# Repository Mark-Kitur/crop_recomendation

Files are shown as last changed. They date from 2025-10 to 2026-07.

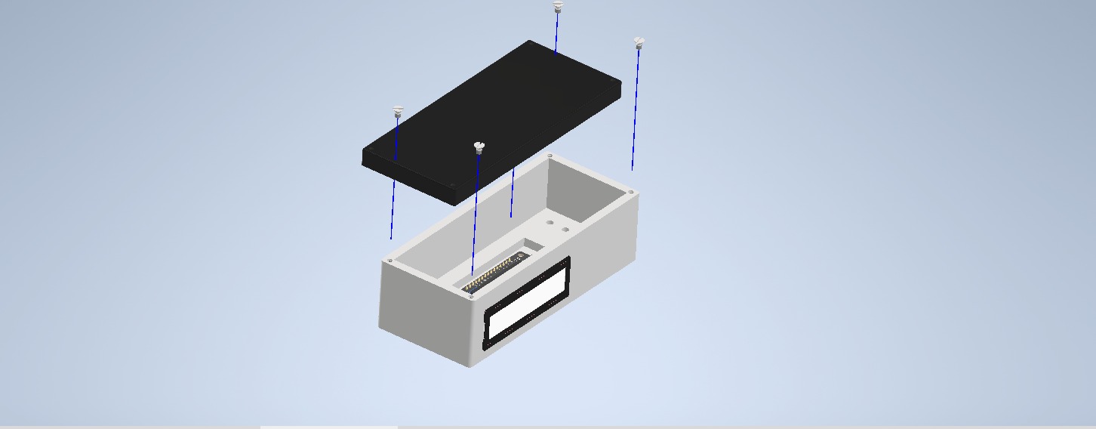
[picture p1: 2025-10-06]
3D Model Images/Assembly.jpeg

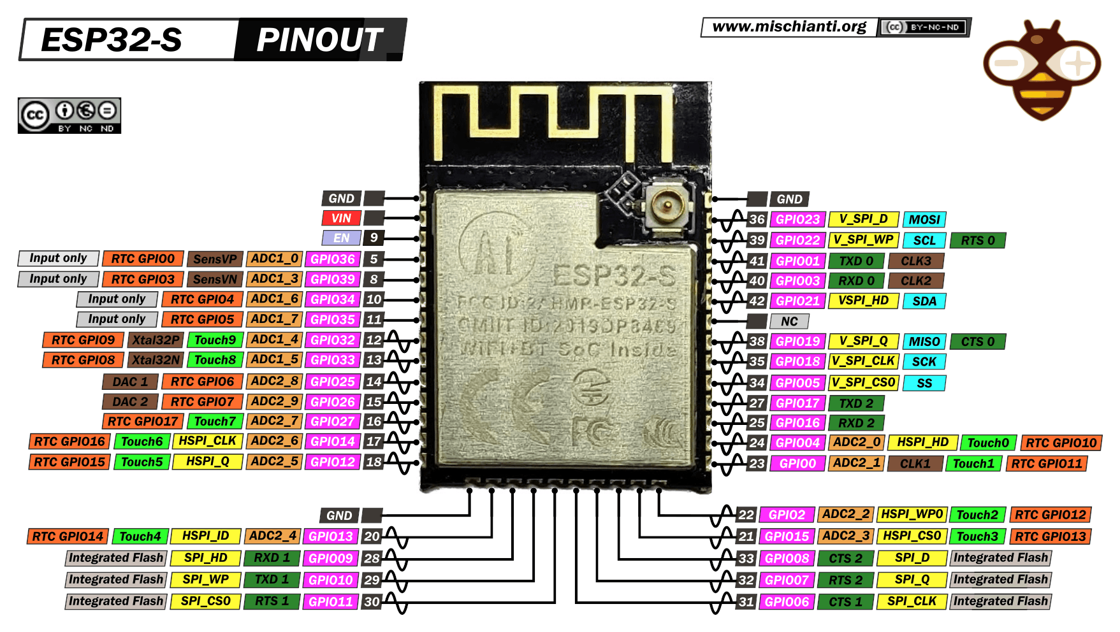
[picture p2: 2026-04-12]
PCB_V2/ESP32-S-pinout-mischianti-high-resolution.png

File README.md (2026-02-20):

**Smart Crop Recommendation System**

link to the video: https://youtu.be/nVsl1SV6peM?si=QAl62YudmvHhIrHM

**Overview**

This project implements a Crop Recommendation System that suggests the most suitable crop to grow based on soil nutrients and environmental conditions. It combines Machine Learning (ML) with IoT (ESP8266 microcontroller) to support precision agriculture.
The workflow:
Collected and preprocessed agricultural data (soil nutrients & climate).
Trained a Random Forest Classifier model to recommend crops.
 Built a Flask web application for user-friendly crop prediction and farming advice.
 Converted the trained ML model to C code (micromlgen) and deployed it on an ESP8266 NodeMCU microcontroller.

Dataset
The dataset includes soil and environmental features:
N: Nitrogen content ratio in soil
P: Phosphorus content ratio in soil
K: Potassium content ratio in soil
Temperature: in °C
Humidity: in %
pH: Soil acidity/alkalinity
Rainfall: in mm

Tech Stack

Machine Learning: Random Forest Classifier (scikit-learn)

Web Framework: Ruby and Flask

Frontend: HTML, CSS (simple UI for predictions)

Microcontroller: ESP8266 (NodeMCU)

TinyML Library: micromlgen for C model export

Flask Web App
The web app allows users to:
Input soil & environmental parameters.
Get the best crop recommendation.
Receive advice on optimizing conditions (nutrients, pH, rainfall, etc.).

**Ruby Backend With ONNX Runtime**
The second deployment path validates language-agnostic inference by converting the trained Random Forest model to ONNX format.

Key Steps

Export trained model from Python → ONNX

Load ONNX model in Ruby using onnxruntime gem

Run inference directly from Ruby backend code

Serve predictions to a lightweight Ruby-based web endpoint or CLI script

Purpose

Demonstrates cross-platform, cross-language model deployment

Makes the engine compatible with Ruby web stacks (e.g., Rails, Sinatra)

Confirms interoperability without retraining or rewriting ML code

Ruby Deployment Capabilities

The Ruby ONNX version can:

Accept soil parameters via a web form or API

Run fast inference locally using ONNX Runtime

Return the crop recommendation + condition improvement notes

**ESP8266 Deployment**
The trained Random Forest model was converted into C code.
Deployed on ESP8266 NodeMCU with:
DHT11 sensor for temperature & humidity.
LCD display to show predicted crop.
Random values (for testing) simulating N, P, K, pH, rainfall.
Feel free to fork, improve, or suggest enhancements. Together, let’s make farming smarter

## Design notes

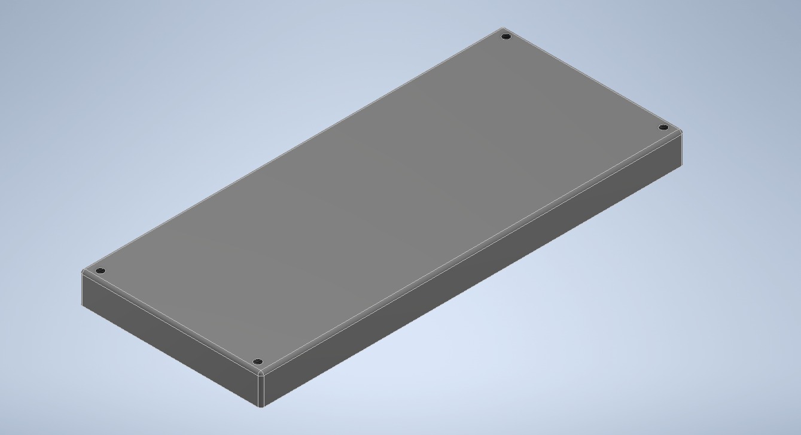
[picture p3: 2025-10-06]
3D Model Images/Top.jpeg

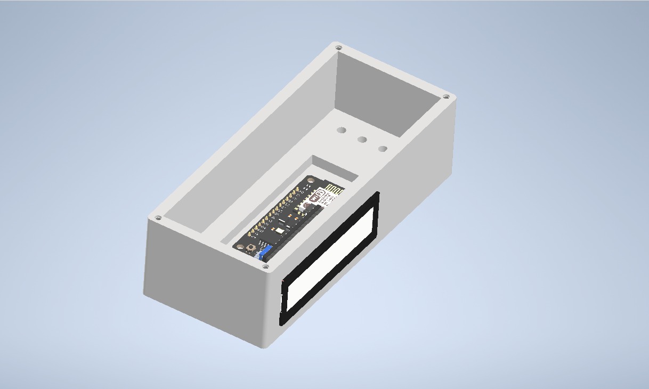
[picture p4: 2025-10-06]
3D Model Images/Base.jpeg

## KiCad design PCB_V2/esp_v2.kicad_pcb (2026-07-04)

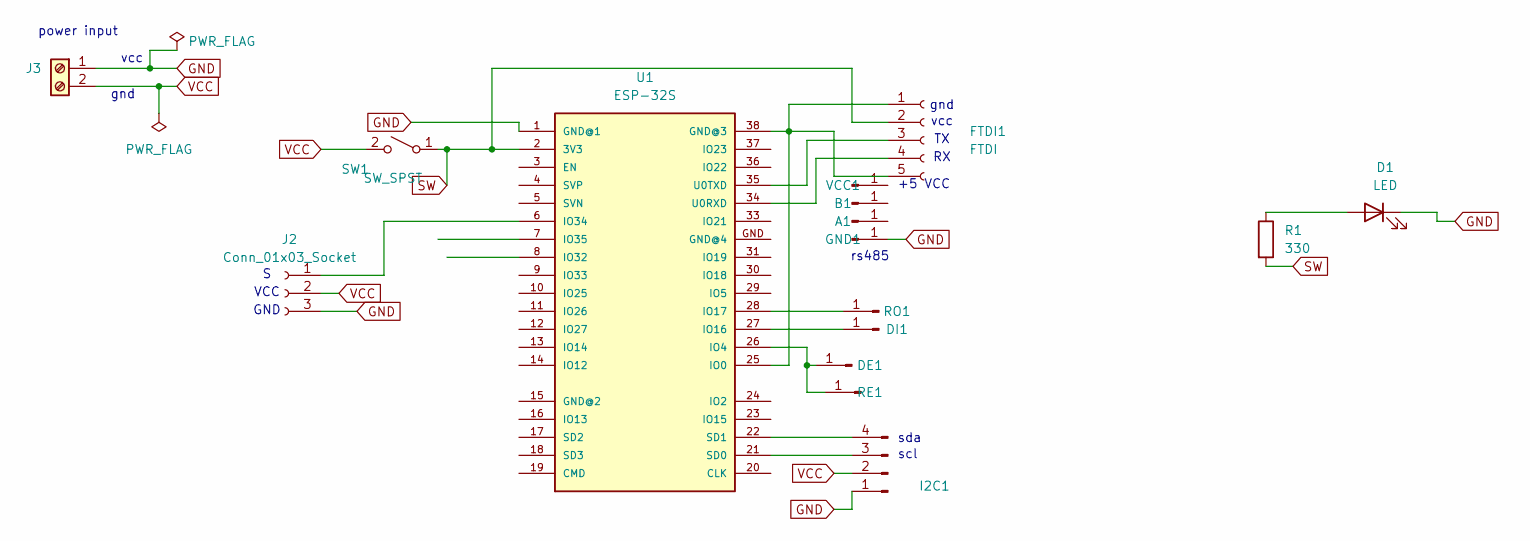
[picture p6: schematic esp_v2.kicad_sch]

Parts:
A1: Conn_01x01_Pin; PinHeader_1x01_P2.54mm_Vertical
B1: Conn_01x01_Pin; PinHeader_1x01_P2.54mm_Vertical
D1: LED; LED_D1.8mm_W3.3mm_H2.4mm
DE1: Conn_01x01_Pin; PinHeader_1x01_P2.54mm_Vertical
DI1: DI; PinHeader_1x01_P2.54mm_Vertical
FTDI1: FTDI; PinSocket_1x05_P2.54mm_Vertical
GND1: Conn_01x01_Pin; PinHeader_1x01_P2.54mm_Vertical
I2C1: Conn_01x04_Pin; PinHeader_1x04_P2.54mm_Vertical
J2: Conn_01x03_Socket; PinSocket_1x03_P2.54mm_Vertical
J3: Screw_Terminal_01x02; TerminalBlock_4Ucon_1x02_P3.50mm_Vertical
R1: 330; R_0815_2038Metric_Pad1.20x4.05mm_HandSolder
RE1: Conn_01x01_Pin; PinHeader_1x01_P2.54mm_Vertical
RO1: Conn_01x01_Pin; PinHeader_1x01_P2.54mm_Vertical
SW1: SW_SPST; SW_DIP_SPSTx01_Slide_6.7x4.1mm_W8.61mm_P2.54mm_LowProfile
U1: ESP-32S
VCC1: Conn_01x01_Pin; PinHeader_1x01_P2.54mm_Vertical

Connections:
GND: D1.1 (K), GND1.1, I2C1.1, J2.3, J3.1, U1.1 (GND@1)
unnamed: D1.2 (A), R1.1
unnamed: DE1.1, RE1.1, U1.26 (IO4)
unnamed: DI1.1, U1.27 (IO16)
unnamed: FTDI1.1, FTDI1.5, U1.25 (IO0), U1.38 (GND@3)
unnamed: FTDI1.3, U1.35 (U0TXD)
unnamed: FTDI1.4, U1.34 (U0RXD)
unnamed: I2C1.3, U1.21 (SD0)
unnamed: I2C1.4, U1.22 (SD1)
unnamed: J2.1, U1.6 (IO34)
unnamed: RO1.1, U1.28 (IO17)
SW: FTDI1.2, R1.2, SW1.1 (A), U1.2 (3V3)
VCC: I2C1.2, J2.2, J3.2, SW1.2 (B)

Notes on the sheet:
sda
+5 VCC
VCC
vcc
scl
gnd
power input
gnd
rs485
GND

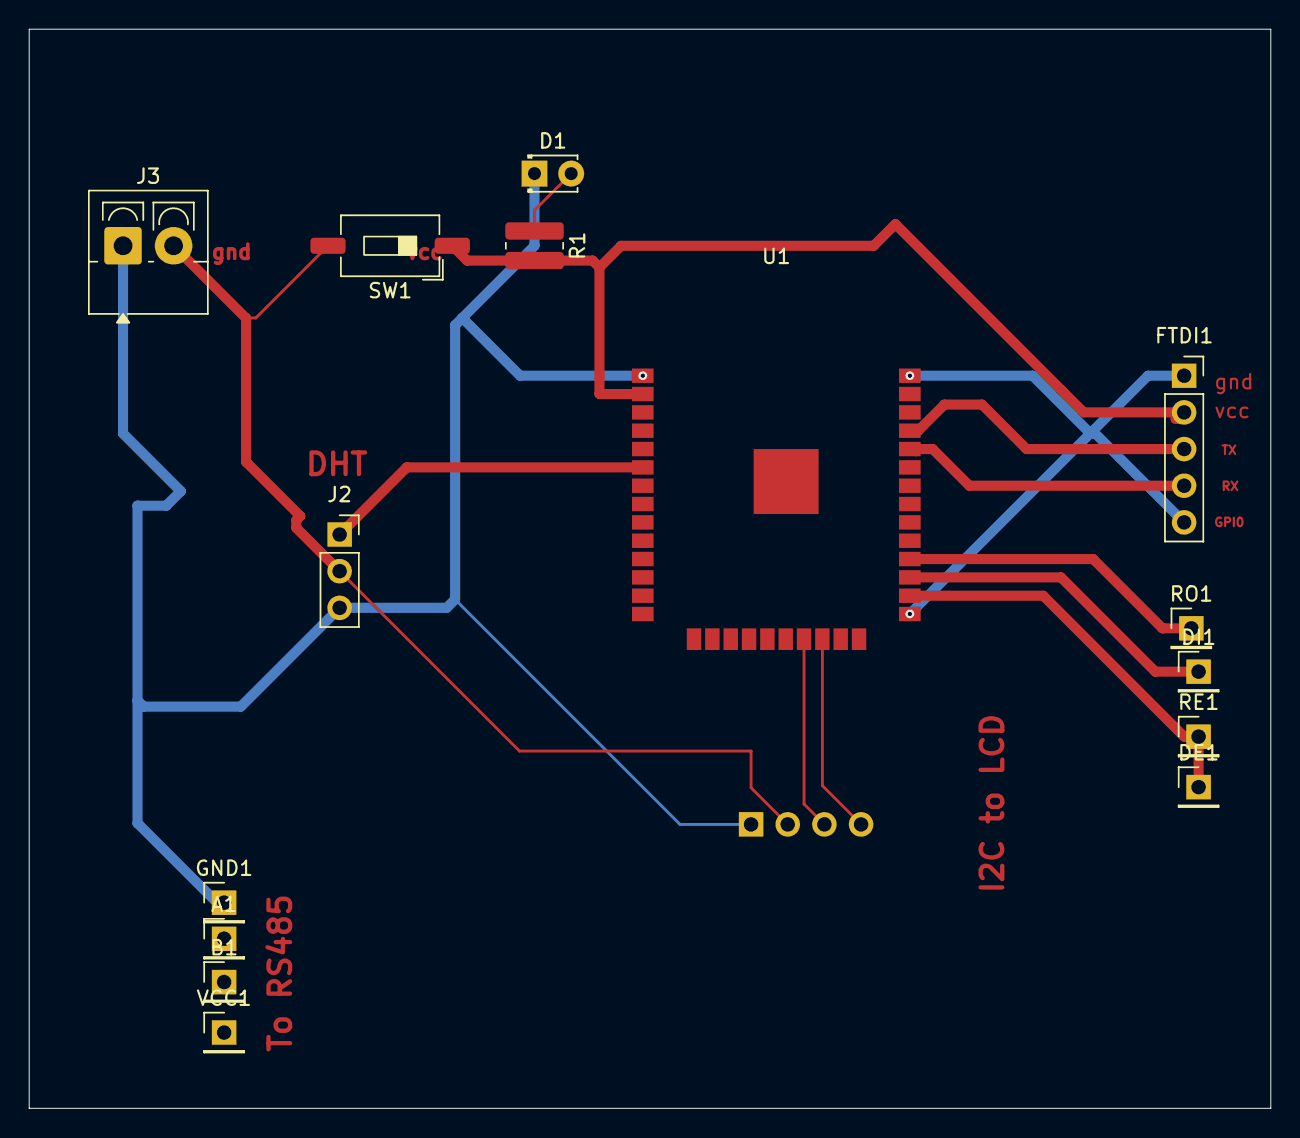
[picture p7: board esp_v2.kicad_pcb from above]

Board: 2 copper layers, 86.0 x 74.8 mm, 16 parts (1 on the bottom side), 13 nets.

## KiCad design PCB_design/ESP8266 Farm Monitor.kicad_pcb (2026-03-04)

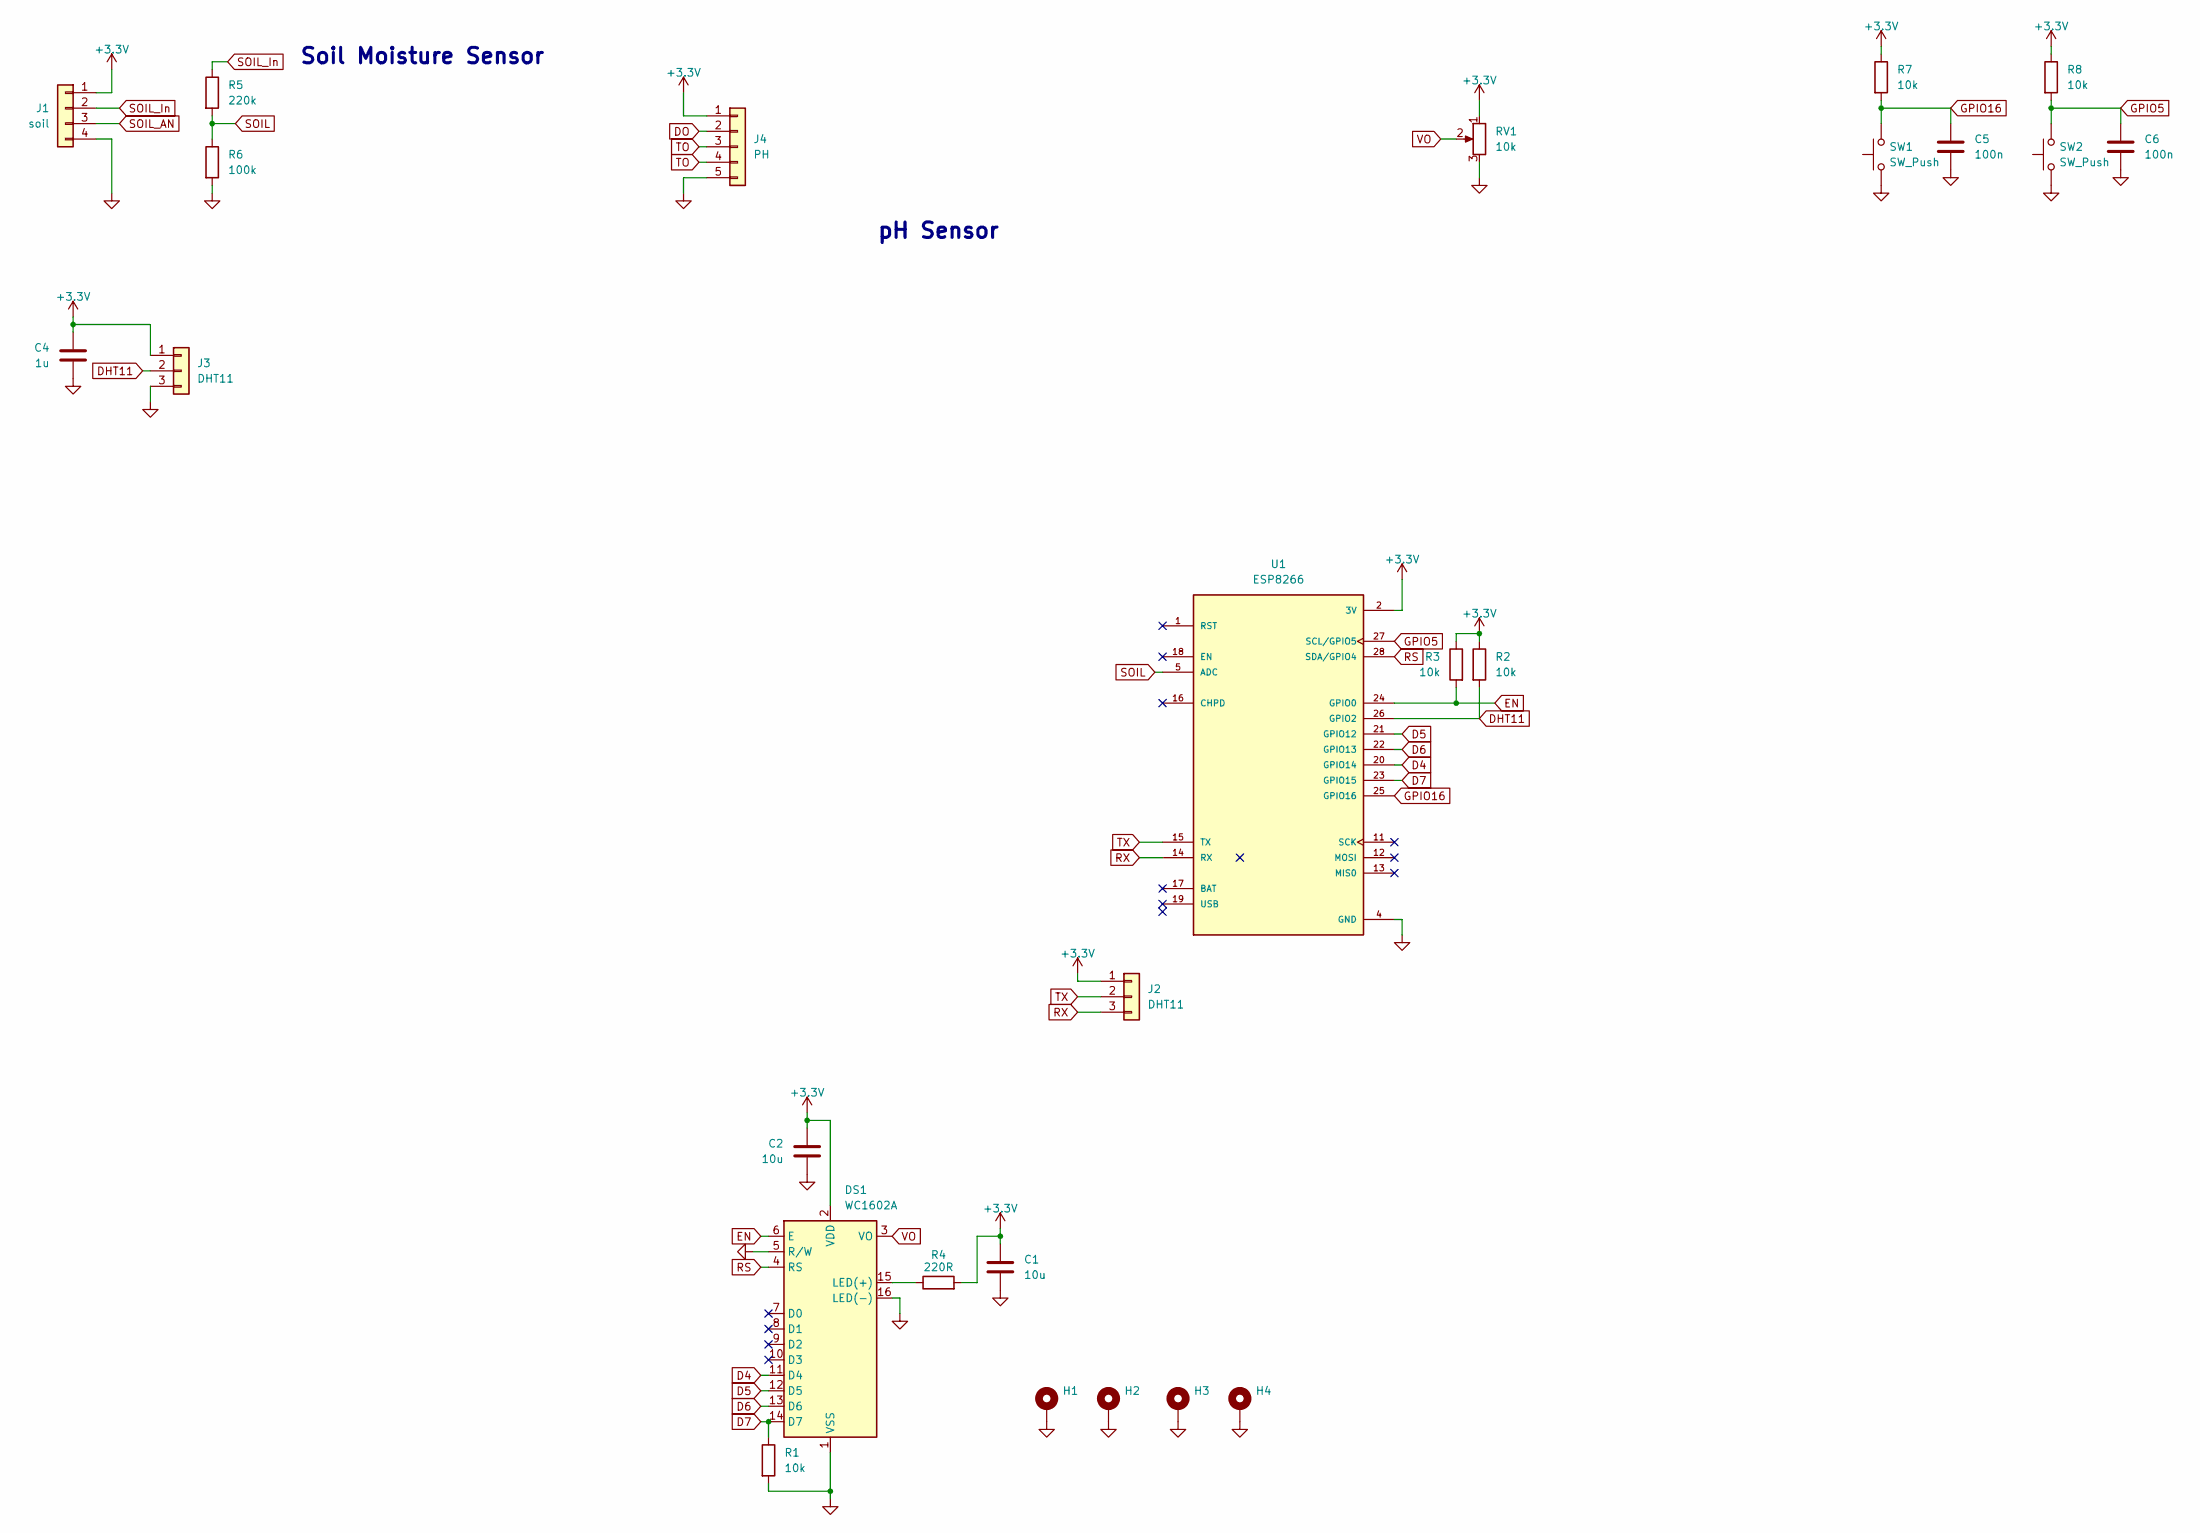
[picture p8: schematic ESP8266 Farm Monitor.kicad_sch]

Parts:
C1, C2: 10u; C_0603_1608Metric
C4: 1u; C_0603_1608Metric
C5, C6: 100n; C_0603_1608Metric
DS1: WC1602A
H1, H2, H3, H4: MountingHole_Pad; MountingHole_2.2mm_M2_Pad
J1: soil; PinHeader_1x04_P2.54mm_Vertical
J2, J3: DHT11; PinHeader_1x03_P2.54mm_Vertical
J4: PH; PinHeader_1x05_P2.54mm_Vertical
R1, R2, R3, R7, R8: 10k; R_0402_1005Metric
R4: 220R; R_Axial_DIN0204_L3.6mm_D1.6mm_P5.08mm_Horizontal
R5: 220k; R_0402_1005Metric
R6: 100k; R_0402_1005Metric
RV1: 10k; TRIM_3362P-1-103
SW1, SW2: SW_Push; SW_SKRPACE010
U1: ESP8266; XCVR_ESP8266

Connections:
+3.3V: C1.1, C2.1, C4.1, DS1.2 (VDD), J1.1, J2.1, J3.1, J4.1, R2.1, R3.1, R4.2, R7.1, R8.1, RV1.1, U1.2 (3V)
D4: DS1.11 (D4), U1.20 (GPIO14)
D5: DS1.12 (D5), U1.21 (GPIO12)
D6: DS1.13 (D6), U1.22 (GPIO13)
D7: DS1.14 (D7), R1.1, U1.23 (GPIO15)
DHT11: J3.2, R2.2, U1.26 (GPIO2)
DO: J4.2
EN: DS1.6 (E), R3.2, U1.24 (GPIO0)
GND: C1.2, C2.2, C4.2, C5.2, C6.2, DS1.1 (VSS), DS1.5 (R/W), DS1.16 (LED(-)), H1.1, H2.1, H3.1, H4.1, J1.4, J3.3, J4.5, R1.2, R6.2, RV1.3, SW1.1, SW2.1, U1.4 (GND)
GPIO5: C6.1, R8.2, SW2.2, U1.27 (SCL/GPIO5)
GPIO16: C5.1, R7.2, SW1.2, U1.25 (GPIO16)
unnamed: DS1.15 (LED(+)), R4.1
RS: DS1.4 (RS), U1.28 (SDA/GPIO4)
RX: J2.3, U1.14 (RX)
SOIL: R5.2, R6.1, U1.5 (ADC)
SOIL_AN: J1.3
SOIL_In: J1.2, R5.1
TO: J4.3, J4.4
TX: J2.2, U1.15 (TX)
VO: DS1.3 (VO), RV1.2

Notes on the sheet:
Soil Moisture Sensor
pH Sensor

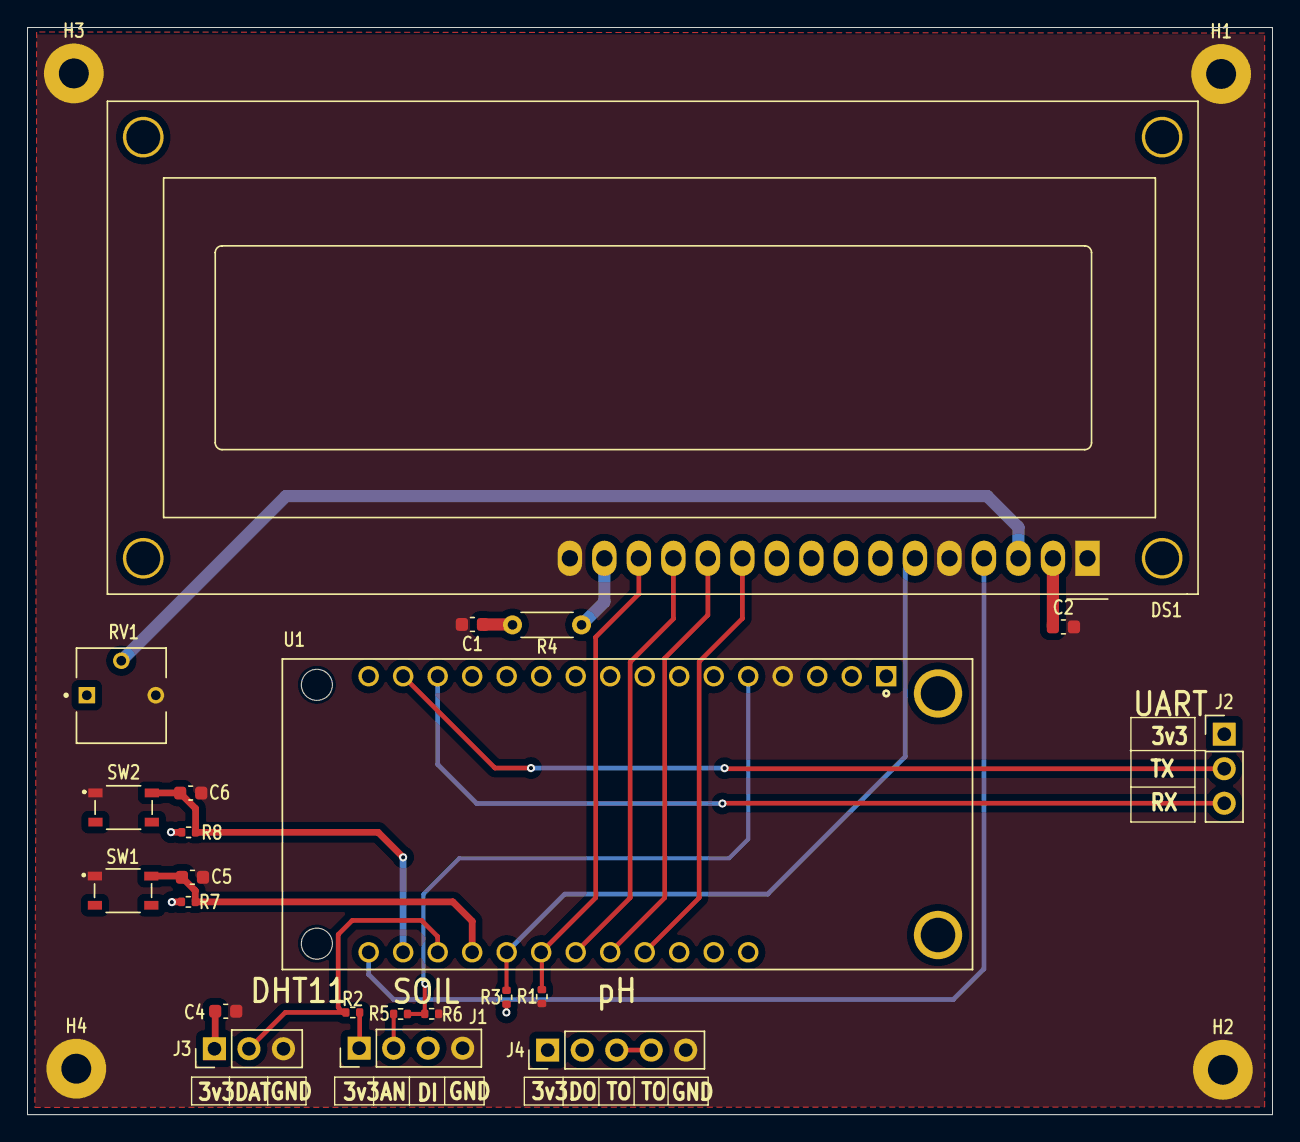
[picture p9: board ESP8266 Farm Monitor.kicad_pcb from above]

Board: 2 copper layers, 91.6 x 80.0 mm, 26 parts (0 on the bottom side), 18 nets.

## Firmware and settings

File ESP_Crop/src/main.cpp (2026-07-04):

#include <Arduino.h>
#include <LiquidCrystal_I2C.h>
#include <DHT.h>

#include "model.h"
#include "7_in_1.h"   // includes RS485 support

// set the LCD number of columns and rows
const int lcdColumns = 16;
const int lcdRows = 2;

LiquidCrystal_I2C lcd(0x27, lcdColumns, lcdRows);  

// #define DHTPIN 2
// #define DHTTYPE DHT11
// DHT dht(DHTPIN, DHTTYPE);

Eloquent::ML::Port::RandomForest RF;

const char* crops[] = {
  "Chickpea","Watermelon","Jute","Muskmelon",
  "Kidneybeans","Mothbeans","Rice","Pomegranate",
  "Maize","Pigeon peas","Grapes","Mango",
  "Coconut","Coffee","Cotton","Apple",
  "Mungbeans","Blackgram","Orange","Lentil",
  "Papaya","Banana"
};

void setup() {
  Serial.begin(9600);
  // dht.begin();
  lcd.init();
  lcd.backlight();

  lcd.setCursor(0,0);
  lcd.print("Smart Farming");
  delay(1500);
  lcd.clear();

  setitup();  // RS485 init
}
void loop() {

  RS485Data data = fetchData();

  float input[7] = {
    data.nitrogen,
    data.phosphorus,
    data.potassium,
    data.temperature,
    data.humidity,
    data.pH,
    data.conductivity
  };

  const char* labels[] = {
    "Nitrogen",
    "Phosphorus",
    "Potassium",
    "Temp",
    "Humidity",
    "pH",
    "EC"
  };

  const char* units[] = {
    "mg/kg",
    "mg/kg",
    "mg/kg",
    "C",
    "%",
    "",
    "uS/cm"
  };

  // Display all sensor readings
  for (int i = 0; i < 7; i++) {
    lcd.clear();

    lcd.setCursor(0, 0);
    lcd.print(labels[i]);

    lcd.setCursor(0, 1);
    lcd.print(input[i], 1);

    if (strlen(units[i]) > 0) {
      lcd.print(" ");
      lcd.print(units[i]);
    }

    delay(2000);
  }

  // Predict crop
  int pred = RF.predict(input);
  const char* crop = crops[pred];

  Serial.print("Predicted Crop: ");
  Serial.println(crop);

  lcd.clear();
  lcd.setCursor(0, 0);
  lcd.print("Recommended");

  lcd.setCursor(0, 1);
  lcd.print(crop);

  delay(5000);
}

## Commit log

2025-05-01 first submission
    [Crop_Recommendation.csv]
2025-09-24 Included the flash() in the html files for a user to be notified when they have provided invalid input. (Input that isn't an integer or a float in this case)
2025-10-05 add button
2025-11-30 adding edge impluse model
    [Crop_Recommendation_randomised.csv]
2026-03-04 adding PCB design
    [ESP8266 Farm Monitor.kicad_pcb, ESP8266 Farm Monitor.kicad_sch]
2026-04-12 adding vesrion of PCB design by Mark-Kitur
    [esp_v2.kicad_pcb, esp_v2.kicad_sch]
2026-04-16 corected the VCC for 7in1
    [esp_v2.kicad_pcb]
2026-04-19 expanded tracks' width
    [esp_v2.kicad_pcb, esp_v2.kicad_sch]
2026-04-21 After our first etching we reiliaze pins were too small . SO we had toenlearge them.
    [esp_v2.kicad_pcb, esp_v2.kicad_sch]
2026-04-26 intergrating 7 in 1 soil sensor
2026-04-26 7 in 1 sensor is now fully functional and working with the model
2026-04-29 validating pCB wrt to ftdi promgrammer
2026-04-29 adding vias to mke back connections
    [esp_v2.kicad_pcb]
2026-05-16 correction on I2C for the lcd
    [esp_v2.kicad_pcb, esp_v2.kicad_sch]
2026-06-11 added power button
    [esp_v2.kicad_sch]
2026-07-04 testseted model on nocdemcu
    [esp_v2.kicad_pcb]
